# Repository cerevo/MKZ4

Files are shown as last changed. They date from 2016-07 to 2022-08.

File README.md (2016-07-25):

MKZ4
====

ワイルドミニ四駆改造キット「MKZ4」用のマニュアル、サンプルプログラム、回路図などをまとめたレポジトリです。

## Folder structure
**Cerevo_MKZ4** ：サンプルプログラム。  
**custom** ：改造用のプログラムや、オリジナルボディのSTLデータ。  
**manual** ：キット付属のマニュアル。  
**schematic**:回路図。  

## Requirement
サンプルプログラムの使用にはVer1.6.8の[Arduino IDE](https://www.arduino.cc/en/Main/OldSoftwareReleases#previous)と[ESP8266 core for Arduino](https://github.com/esp8266/Arduino)のインストールが必要です。  
インストールの説明はそれぞれのURLを参照してください。

## Demo
/Cerevo_MKZ4/Cerevo_MKZ4.inoがサンプルプログラムになります。  
ESP8266を追加したArduino IDEでビルドしてください。  
※ボードマネージャーのesp8266のVerは2.2.0で動作確認をしています。  

## Licence

[BSD 3-Clause License](https://opensource.org/licenses/BSD-3-Clause)

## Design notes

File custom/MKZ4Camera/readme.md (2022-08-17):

# About
MKZ4にESP32カメラを接続し、カメラの画像を見ながらラジコン操作ができるプロジェクトです。
M5 cameraXにて動作確認をしています。他のデバイスを使う場合はCameraWebServer.ino内で対象のカメラモデルを選択してください。

MKZ4との接続は以下の通りです。また[Cervoブログの記事](https://tech-blog.cerevo.com/archives/12014/)も参照してみてください。（制作的なことはざっくりとしか書いていないです。すみません。）

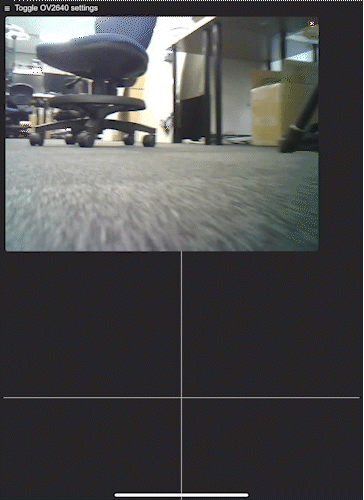
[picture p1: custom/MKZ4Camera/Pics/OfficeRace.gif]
Office Circuit


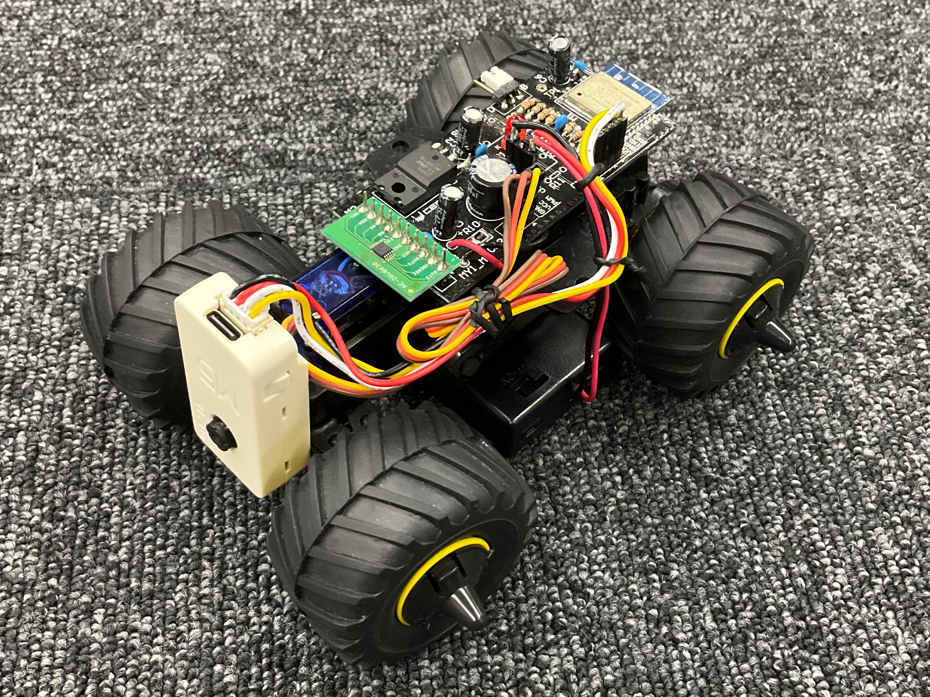
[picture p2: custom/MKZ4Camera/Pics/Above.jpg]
View from above


## System
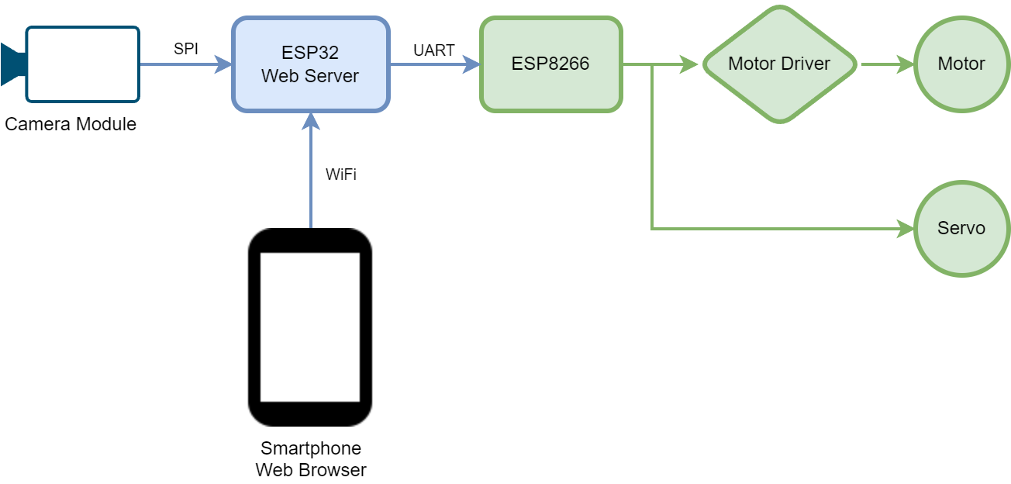
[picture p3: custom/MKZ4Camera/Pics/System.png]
System


## Important Note
- 電源スイッチを入れるときにEP32とUART端子が接続されているとMKZ4基板が起動しない（LEDが点灯しない）ため、UART端子を外してから電源スイッチを入れ、それからUART端子を再度接続するようにしてください。
- Arduino環境でArduino-ESP32をセットアップする場合、package_esp32_index.jsonのダウンロード先に注意してください。古い資料だと以下のURLになっていますが、ESP32 Arduino v1.0.6以降更新されていないようです。
`https://dl.espressif.com/dl/package_esp32_index.json`
Espressifのドキュメンテーションにあるとおり、以下のURLを設定する必要があります。
`https://docs.espressif.com/projects/arduino-esp32/en/latest/installing.html`
古いindex.jsonのURLが入っているとArduino-ESP32のバージョンがアップデートされず、ビルド出来なくなります。

## Building Project
- MKZ4(ESP8266)のプロジェクト（Cerevo_MKZ4_UARTまたはCerevo_MKZ4_UART_platformio）をビルドする。
- ESP32カメラのプロジェクトをビルドする（CameraWebServerまたはMKZ4_Camera_ESP32_platformio)
- ビルド方法はそれぞれのフォルダ内のReadme参照

## Wiring
ESP32カメラ（Grobeコネクタ）とMKZ4を以下のように接続します。
| ESP32カメラ(Grobe) | MKZ4  |
| --- |---|
| Pin1(Yellow) | TDX |
| Pin2(White) | RDX |
| Pin3(Black) | GND |
| Pin4(Red) | Batt+ |

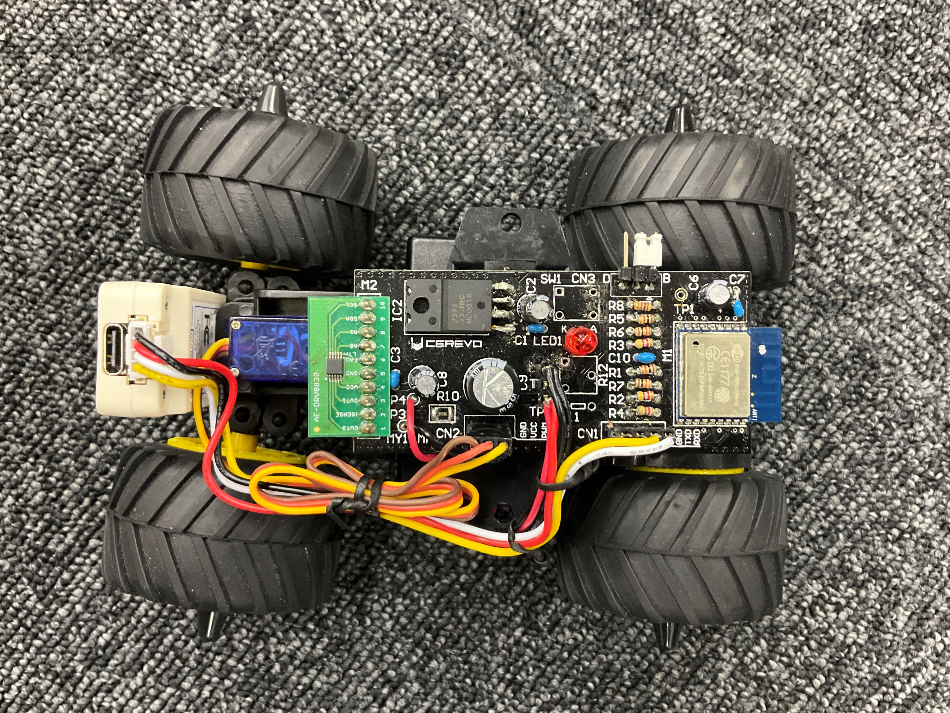
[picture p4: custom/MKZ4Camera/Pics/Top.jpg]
Top

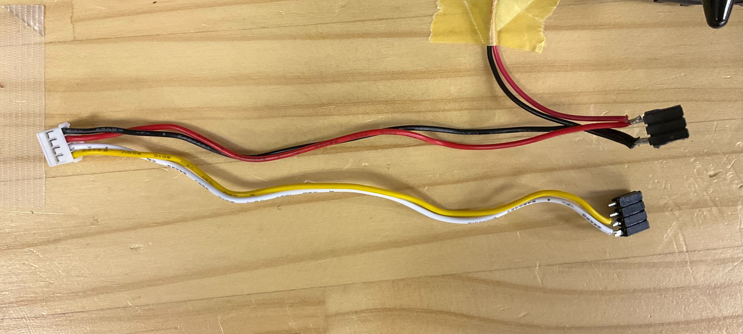
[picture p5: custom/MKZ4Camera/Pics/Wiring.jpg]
Wiring


## セットアップ起動手順
- 上記Wiringを済ませ配線したらMKZ4側のUART端子を外しておく
- 電池ボックスの電源を入れる
- MKZ4基板上のLED点灯を確認する。
- UART端子を接続
- AP接続の場合mkz4camというWiFiアクセスポイントがスマートフォンから見えるはずなので接続する。PW不要、インターネットに接続されていないと警告が出るかもしれませんが無視します。
- Webブラウザを立ち上げ、**192.168.4.1** と入力すると操作画面が見えます。
- Settingsタブを開き、一番下のStartStreamボタンを押すとESP32Cameraの画像が見えます。
- 画面下部の十字エリア中心部をタッチし（指を離さないまま）上の方にスライドします。MKZ4のモーターが回りましたか？
- 同様に左右方向に指をスライドさせるとステアリングが動きます。
- 下方向にスライドさせるとモーターが反転して回ります。

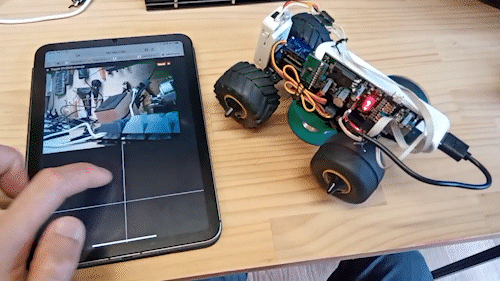
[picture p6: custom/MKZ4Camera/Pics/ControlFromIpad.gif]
From Ipad


## 技術情報
[M5 cameraX pinout](https://docs.m5stack.com/en/unit/m5camera_x)

今回参照したカメラウェブサーバのサンプルです。ESP32版もあります。
[Official CameraWebServer.ino sample](https://github.com/espressif/arduino-esp32/tree/master/libraries/ESP32/examples/Camera/CameraWebServer)

[ESP-IDFでのWebsocket実装情報](https://docs.espressif.com/projects/esp-idf/en/latest/esp32/api-reference/protocols/esp_http_server.html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)

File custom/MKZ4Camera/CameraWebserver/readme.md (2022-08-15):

# About
MKZ4にESP32カメラを接続し、カメラの画像を見ながらラジコン操作ができるプロジェクトです。
M5 cameraXにて動作確認をしています。他のデバイスを使う場合はCameraWebServer.ino内で対象のカメラモデルを選択してください。
MKZ4との接続は以下の通りです。またCervoブログの記事も参照してみてください。（制作的なことはざっとしか書いてないです。すみません。）

## Important Note
- 電源スイッチを入れるときにEP32とUART端子が接続されているとMKZ4基板が起動しない（LEDが点灯しない）ため、UART端子を外してから電源スイッチを入れ、それからUART端子を再度接続するようにしてください。
- Arduino環境でArduino-ESP32をセットアップする場合、package_esp32_index.jsonのダウンロード先に注意してください。古い資料だと以下のURLになっていますが、ESP32 Arduino v1.0.6以降更新されていないようです。
`https://dl.espressif.com/dl/package_esp32_index.json`
Espressifのドキュメンテーションにあるとおり、以下のURLを設定する必要があります。
`https://docs.espressif.com/projects/arduino-esp32/en/latest/installing.html`
古いindex.jsonのURLが入っているとArduino-ESP32のバージョンがアップデートされず、ビルド出来なくなります。

## Build
- [Arduino-ESP32環境](https://docs.espressif.com/projects/arduino-esp32/en/latest/installing.html)をセットアップ
- WIFIAP_ENABLEDを有効にしていると（デフォルト）espcamのWiFiアクセスポイントが立ちあがります。自分のWiFiにつなぎたい場合はWIFIAP_ENABLEDを無効にしたうえでssid, passwordを入力してください。
- Tools > Board > ESP32 Wrover Moduleを選択
- Verify、Upload
- 追加ライブラリは特に必要ありません。

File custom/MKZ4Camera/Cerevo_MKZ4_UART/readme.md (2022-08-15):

# Cerevo MKZ4 controller with UART
こちらのスケッチはMKZ4をESP32カメラから操作するためのものです。このプログラムはUART経由で制御が可能です。

## Important Note
電源スイッチを入れるときにUART端子が接続されているとMKZ4基板が起動しない（LEDが点灯しない）ため、UART端子を外してから電源スイッチを入れ、それからUART端子を再度接続するようにしてください。

## How to build
オリジナルのMKZ4と同じくボードマネージャからESP8266を選択してVerifyしたあと、Uploadしてください。特に追加のライブラリは必要ありません。

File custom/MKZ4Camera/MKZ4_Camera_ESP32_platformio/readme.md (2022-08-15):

# About
MKZ4にESP32カメラを接続し、カメラの画像を見ながらラジコン操作ができるプロジェクトです。
M5 cameraXにて動作確認をしています。他のデバイスを使う場合はCameraWebServer.ino内で対象のカメラモデルを選択してください。
MKZ4との接続は以下の通りです。またCervoブログの記事も参照してみてください。（制作的なことはざっとしか書いてないです。すみません。）

## Important Note
- 電源スイッチを入れるときにEP32とUART端子が接続されているとMKZ4基板が起動しない（LEDが点灯しない）ため、UART端子を外してから電源スイッチを入れ、それからUART端子を再度接続するようにしてください。

## Build
- VSCodeからPlatformioをインストールしてください。
- PlatformIO: Buildでビルド
- PlatformIO: Upload
- 追加ライブラリは特に必要ありません。

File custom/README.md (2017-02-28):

## Description

- Cerevo_MKZ4_CDS_V02 :本体にLEDとCDSを追加して、暗くなったら自動でLEDが点灯するサンプル。

- Cerevo_MKZ4_LED-light :本体にLEDを追加してPWMで点灯させるサンプル。  

- Cerevo_MKZ4_LED-light2 :本体にLEDライト（フロントのみを想定）追加して走行時明るく光らせるサンプル。

- Cerevo_MKZ4_calib :UARTからoffset,left,rightの値を修正できるコマンドを追加。

- milkcocoa_esp8266 ：milkcocoaを使うサンプル(ESP側）。  

- milkcocoa_javascript ：milkcocoaを使うサンプル(javascript側)。  

- MKZ4_example2 :スマートフォンの傾きでミニ四駆を操作するサンプル。  

- remote_led_switch_example :ブラウザからLEDをON/OFFするサンプル。  

- MKZ4_OriginalBody.stl :オリジナルボディの3DCADのデータ。  

---
### キャリブコマンドの使い方

#### 前準備

1. Cerevo_MKZ4_calib.inoを書きこむ
2. ESP8266とUARTで接続する(ボーレート:115200 , デリミタ:CR+LF)

#### コマンド

* offset角度修正コマンド:前進させた時に少し右や左に曲がってしまうのを修正する  

コマンド  
offset+space+角度[CR][LF]  

ex)  
offset 10[CR][LF] //10°右にずらす  
offset -20[CR][LF] //20°左にずらす   
  
* 左ステアリング角度修正コマンド:左に曲がる角度を修正する　デフォルト65°

コマンド  
left+space+角度[CR][LF]  

ex)  
left 60[CR][LF] //左ステアリング角度を浅くする場合  
left 70[CR][LF] //左ステアリング角度を深くする場合  
   
* 右ステアリング角度修正コマンド:右に曲がる角度を修正する　デフォルト110°  

コマンド  
right+space+角度[CR][LF]  

ex)  
right 105[CR][LF] //右ステアリング角度を浅くする場合   
right 115[CR][LF] //右ステアリング角度を深くする場合

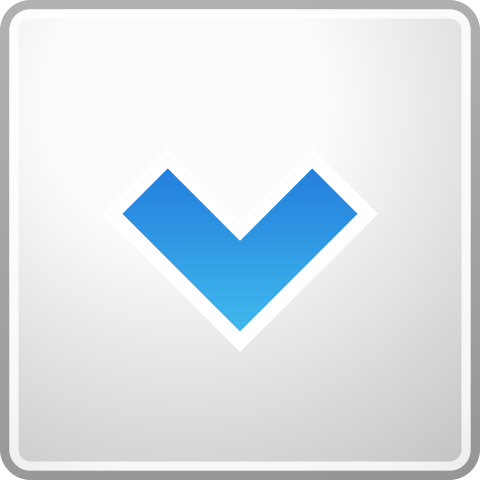
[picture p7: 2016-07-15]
custom/milkcocoa_javascript/image/back.png

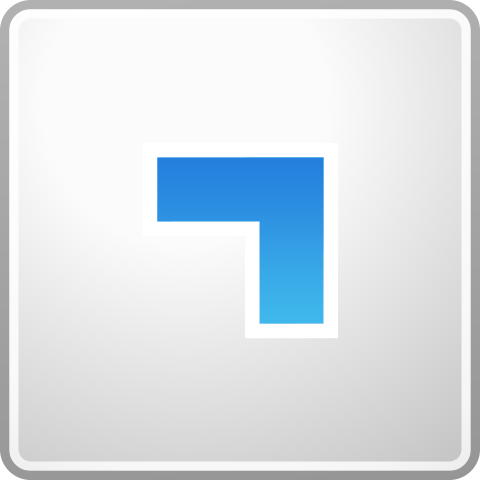
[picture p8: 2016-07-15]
custom/milkcocoa_javascript/image/f_right.png

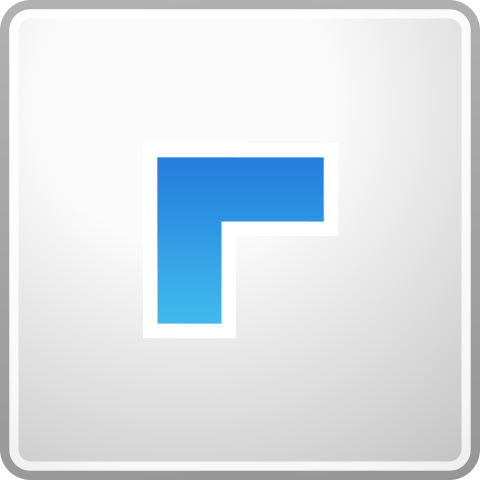
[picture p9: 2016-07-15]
custom/milkcocoa_javascript/image/f_left.png

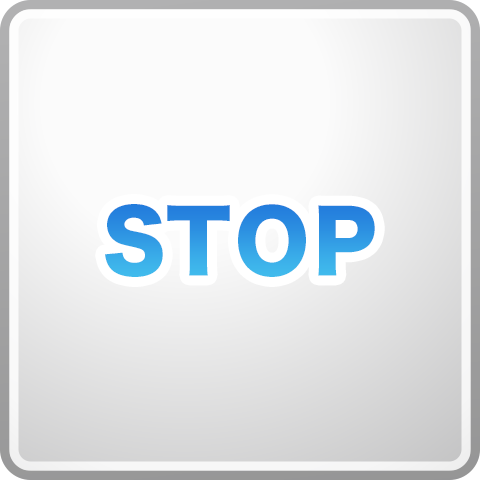
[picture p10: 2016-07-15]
custom/milkcocoa_javascript/image/stop.png

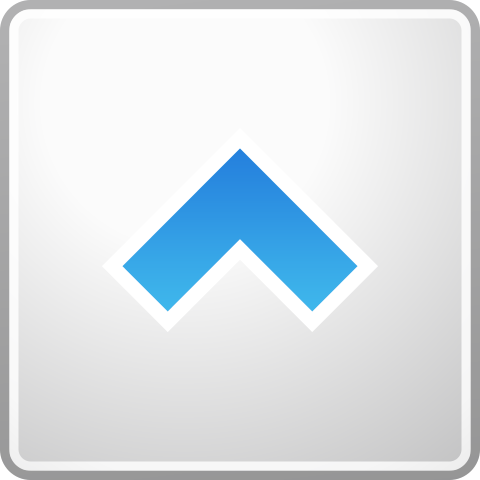
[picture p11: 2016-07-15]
custom/milkcocoa_javascript/image/forward.png

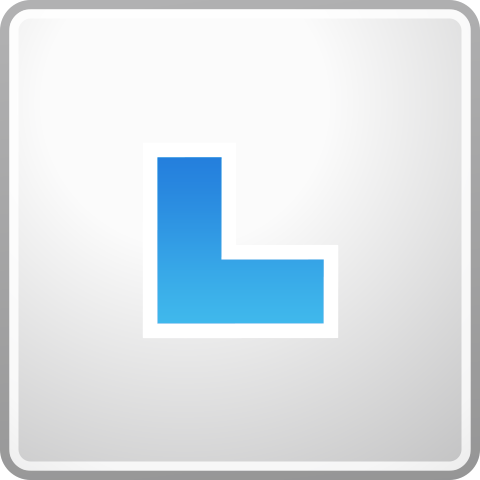
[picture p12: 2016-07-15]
custom/milkcocoa_javascript/image/b_left.png

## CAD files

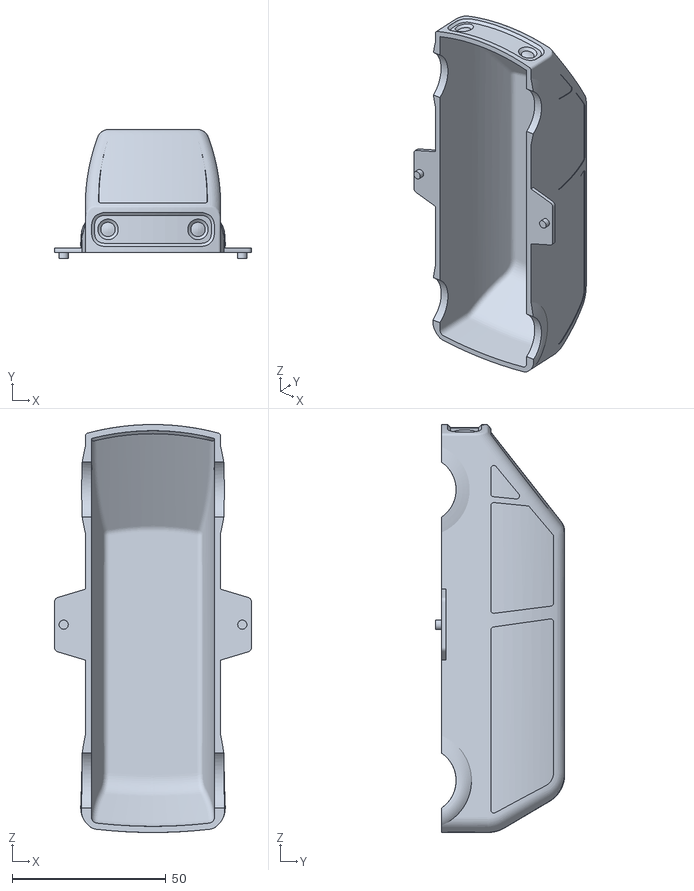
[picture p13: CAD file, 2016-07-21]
custom/MKZ4_OriginalBody.stl
64.0 x 42.0 x 132.5

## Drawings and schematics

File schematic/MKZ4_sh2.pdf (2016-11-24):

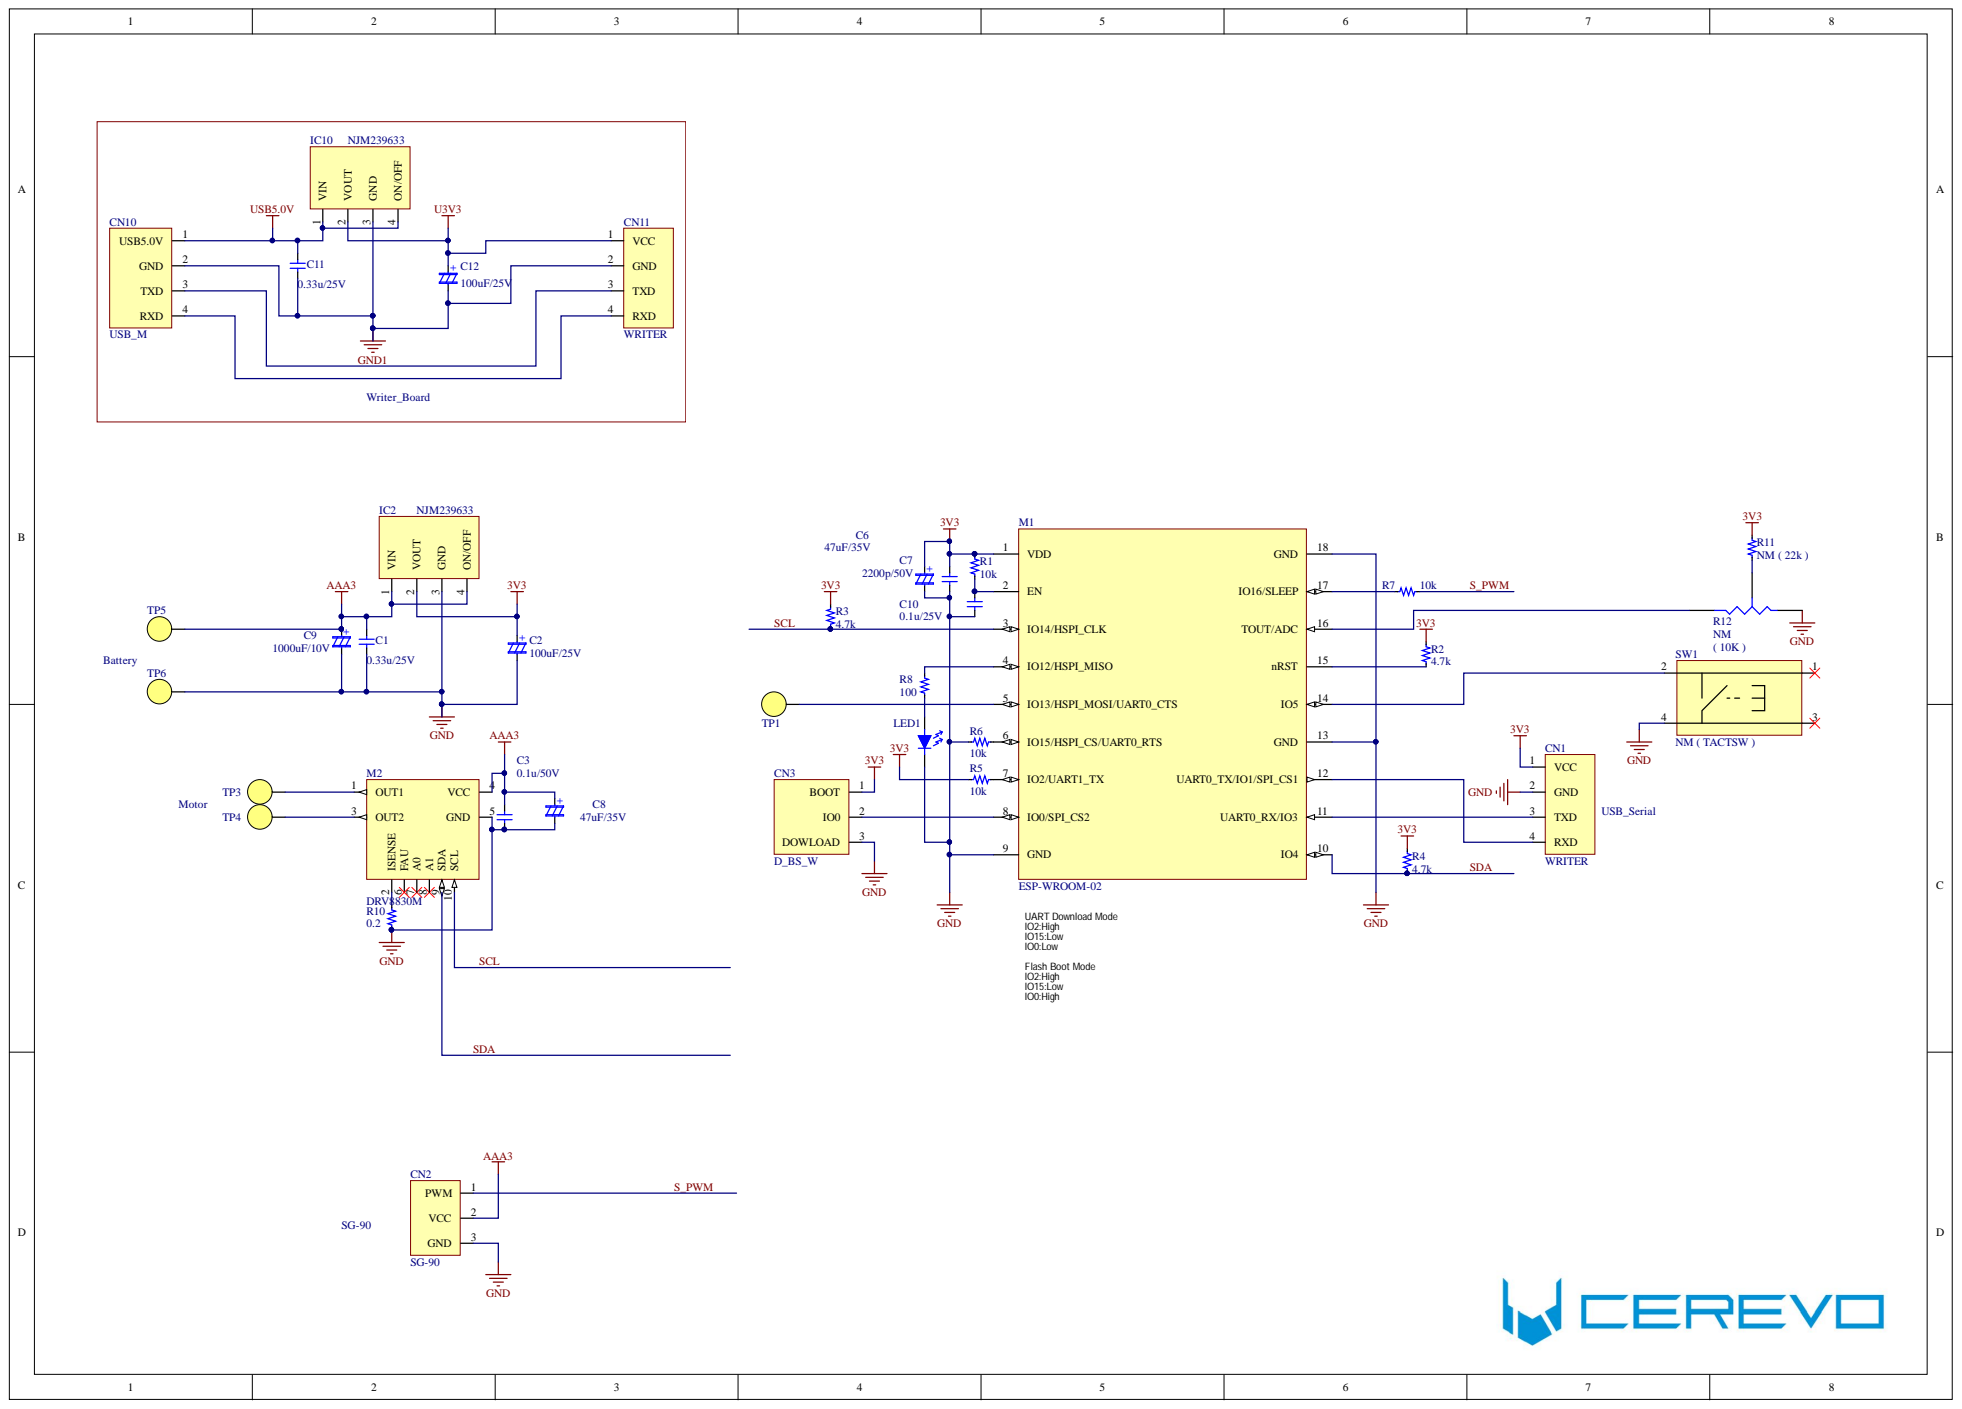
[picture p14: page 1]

UART Download Mode IO2:High IO15:Low

IO0:Low
Flash Boot Mode IO2:High
IO15:Low IO0:High

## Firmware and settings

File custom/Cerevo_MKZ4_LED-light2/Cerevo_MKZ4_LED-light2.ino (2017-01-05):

/*
 * Copyright (c) 2015, Majenko Technologies
 * All rights reserved.
 * 
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
 * * Neither the name of Majenko Technologies nor the names of its
 *   contributors may be used to endorse or promote products derived from
 *   this software without specific prior written permission.
 * 
 * THIS SOFTWARE IS PROVIDED BY THE COPYRIGHT HOLDERS AND CONTRIBUTORS "AS IS" AND
 * ANY EXPRESS OR IMPLIED WARRANTIES, INCLUDING, BUT NOT LIMITED TO, THE IMPLIED
 * WARRANTIES OF MERCHANTABILITY AND FITNESS FOR A PARTICULAR PURPOSE ARE
 * DISCLAIMED. IN NO EVENT SHALL THE COPYRIGHT HOLDER OR CONTRIBUTORS BE LIABLE FOR
 * ANY DIRECT, INDIRECT, INCIDENTAL, SPECIAL, EXEMPLARY, OR CONSEQUENTIAL DAMAGES
 * (INCLUDING, BUT NOT LIMITED TO, PROCUREMENT OF SUBSTITUTE GOODS OR SERVICES;
 * LOSS OF USE, DATA, OR PROFITS; OR BUSINESS INTERRUPTION) HOWEVER CAUSED AND ON
 * ANY THEORY OF LIABILITY, WHETHER IN CONTRACT, STRICT LIABILITY, OR TORT
 * (INCLUDING NEGLIGENCE OR OTHERWISE) ARISING IN ANY WAY OUT OF THE USE OF THIS
 * SOFTWARE, EVEN IF ADVISED OF THE POSSIBILITY OF SUCH DAMAGE.
 */

/* Create a WiFi access point and provide a web server on it. */

#include <ESP8266WiFi.h>
#include <WiFiClient.h> 
#include <ESP8266WebServer.h>

/* Set these to your desired credentials. */
const char *ssid = "MKZ4_Light2_**";
const char *password = "";

ESP8266WebServer server(80);
ESP8266WebServer server_8080(8080);

/* set I2C library*/
#include <Wire.h>
#define ADDR1  0x64

#define command_start  0
#define command_stop   1
#define command_back  2
#define forward       0x01
#define reverse       0x02
#define servo_left    65
#define servo_right   115

#define LED_H       (digitalWrite( 12, HIGH ))
#define LED_L       (digitalWrite( 12, LOW ))

//TP1 GPIO13
#define HLED_H       (analogWrite( 13, 0 ))
#define HLED_M       (analogWrite( 13, 768 ))

char state = command_stop;
int offset = 0;

String form ="<html>"
"<head>"
"<meta name=\"viewport\" content=\"width=device-width, initial-scale=1, minimum-scale=1, maximum-scale=1\">"
"<style>"
"* { padding: 0; margin: 0; }"
"body { background-color: #0097C1; }"
"</style>"
"</head>"
"<body>"
"<div style=\"position:fixed;top: 50pt; text-align:center; width: 100%; color:white; font-size:300%; font-weight:bold; text-transform:uppercase; font-family:sans-serif\" id=\"value\">connected</div>"
"<form action=\"\" target=\"tif\" id=\"form\">"
"<iframe src=\"javascript: false;\" style=\"display: none;\" name=\"tif\" id=\"tif\"></iframe>"
"</form>"
"<script>"
"var offset = 50;"
"document.body.style.height = document.body.clientHeight + offset + \'px\';"
"document.body.style.width = document.body.clientWidth + offset + \'px\';"
"document.getElementsByTagName(\"html\")[0].style.height = document.body.style.height + \'px\';"
"document.getElementsByTagName(\"html\")[0].style.width = document.body.style.width + \'px\';"
"var moveHomePosition = function() {"
    "document.body.scrollTop = offset / 2;"
    "document.body.scrollLeft = offset / 2;"
"};"
"setTimeout(moveHomePosition, 500);"
"var startX = 0;var startY = 0;var command =\'/stop\';"
"var threshold = 40;"
"var esp_port = \'http://192.168.4.1:8080\';"
"var el_form = document.getElementById(\'form\');"
"document.body.ontouchstart = function(event) {"
    "startX = event.touches[0].clientX;"
    "startY = event.touches[0].clientY;"
"};"
"document.body.ontouchmove = function(event) {"
    "var x = parseInt(event.touches[0].clientX - startX);"
    "var y = parseInt(event.touches[0].clientY - startY);"
    "var url = null;"
    "if (x < (threshold * -1)) {"
       "if (y < (threshold * -1)){"
          "url = \'/left<br>forward\';"
       "} else if (y > threshold) {"
          "url = \'/left<br>back\';"
       "}else {"
        "url = \'/left\';"
       "}"
    "} else if (x > threshold) {"
       "if (y < (threshold * -1)) {"
          "url = \'/right<br>forward\';"
      "} else if (y > threshold) {"
          "url = \'/right<br>back\';"
      "}else{"
          "url = \'/right\';"
      "}"
     "} else {"
        "if (y < (threshold * -1)) {"
            "url = \'/forward\';"
        " } else if (y > threshold) {"
            "url = \'/back\';"
        "}"
     "}"
    "if (command != url) {"
      "if (url) {"
          "el_form.action = esp_port + url.replace(\"<br>\",\"\");"
          "el_form.submit();"
          "document.getElementById(\'value\').innerHTML = url.replace(\"/\",\"\");"
      "}"
    "}"
    "command = url;"
"};"
"document.body.ontouchend = function(event) {"
    "el_form.action = esp_port + \'/stop\';"
    "el_form.submit();"
    "setTimeout(moveHomePosition, 50);"
   "document.getElementById(\'value\').innerHTML = \'stop\';"
"};"
"</script>"
"</body>"
"</html>";

/* Just a little test message.  Go to http://192.168.4.1 in a web browser
 * connected to this access point to see it.
 */
void setup() {
	delay(1000);
	Serial.begin(115200);
	Serial.println();
	Serial.print("Configuring access point...");

  Wire.begin(4, 14);
  delay(40);
  
	/* You can remove the password parameter if you want the AP to be open. */
	WiFi.softAP(ssid, password);

	IPAddress myIP = WiFi.softAPIP();
	Serial.print("AP IP address: ");
	Serial.println(myIP);
 
	server.on("/", handleRoot);
  server_8080.on("/stop", handle_stop);
  server_8080.on("/forward", handle_forward);
  server_8080.on("/back", handle_back);
  server_8080.on("/left", handle_left);
  server_8080.on("/right", handle_right);
  server_8080.on("/leftforward", handle_f_left);
  server_8080.on("/rightforward", handle_f_right);
  server_8080.on("/leftback", handle_b_left);
  server_8080.on("/rightback", handle_b_right);
 
	server.begin();
  server_8080.begin();
  
	Serial.println("HTTP server started");
  pinMode(16,OUTPUT);
  pinMode(12,OUTPUT);

  LED_H;
  HLED_M;
    
  delay(100);
}

void loop() {
	server.handleClient();
  server_8080.handleClient();
}


void handleRoot() {
  server.send(200, "text/html", form);
}


void handle_stop() {
  Serial.print("stop\r\n");
  LED_L;
  HLED_M;
    stop_motor();
    state = command_stop;
  LED_H;
  server_8080.send(200, "text/html", "");
}

void handle_forward() {
 Serial.print("forward\r\n");
  HLED_H;
  drive();
  servo_control(90);
  server_8080.send(200, "text/html", "");
}

void handle_back() {
  Serial.print("back\r\n");
  HLED_H;
  back();
  servo_control(90);
}

void handle_left(){
  Serial.print("left\r\n");
  HLED_H;
  servo_control(servo_left);
  server_8080.send(200, "text/html", "");
}

void handle_right(){
  Serial.print("right\r\n");
  HLED_H;
  servo_control(servo_right);
  server_8080.send(200, "text/html", "");
}

void handle_f_left(){
  Serial.print("f_left\r\n");
  HLED_H;
  drive();
  servo_control(servo_left);
  server_8080.send(200, "text/html", "");
}

void handle_f_right(){
  Serial.print("f_right\r\n");
  HLED_H;
  drive();
  servo_control(servo_right);
 server_8080.send(200, "text/html", "");
}

void handle_b_left(){
  Serial.print("b_left\r\n");
  HLED_H; 
  back();
  servo_control(servo_left );
  server_8080.send(200, "text/html", "");
}


void handle_b_right(){
  Serial.print("b_right\r\n");
  HLED_H;
  back();
  servo_control(servo_right);
  server_8080.send(200, "text/html", "");
}

void drive(){
    if(state == command_back){
     stop_motor();

     delay(10);

     start_motor();
  
  }else if(state == command_stop){
    start_motor();
  }
  state = command_start;
}

void back(){
    if(state == command_start){
     stop_motor();
     delay(10);
     reverse_motor();
  }else if(state == command_stop){
    reverse_motor();
  }
  state = command_back;
}

void start_motor(){
  char i, volt;
  volt = 0x20;
  for(i=0;i<5;i++){ 
    volt = volt + ((0x40)*i);
    volt = volt | forward;
    motor_func(ADDR1 , volt);
    delay(10);
  }
}

void reverse_motor(){
    char i, volt;
  volt = 0x20;
  for(i=0;i<5;i++){ 
    volt = volt + ((0x40)*i);
    volt = volt | reverse;
    motor_func(ADDR1 , volt);
    delay(10);
  }
}

void stop_motor(){
  motor_func(ADDR1 , 0x18);
  delay(10);
  motor_func(ADDR1 , 0x1B);
  delay(10);
}

void motor_func(char add , char duty){
  Wire.beginTransmission(add);
  Wire.write(0x00);
  Wire.write(duty);
  Wire.endTransmission();
}

void servo_control(int angle){
int microsec,i;
      LED_L;
      microsec = (5*(angle+offset))+ 1000;
       
      for(i=0; i<20 ;i++){
        digitalWrite( 16, HIGH );
        delayMicroseconds( microsec ); 
        digitalWrite( 16, LOW );
        delayMicroseconds( 10000 - microsec ); 
      }
      LED_H;
}

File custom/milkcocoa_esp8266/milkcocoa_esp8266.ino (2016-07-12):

#include <ESP8266WiFi.h>
#include <Milkcocoa.h>


#include <Wire.h>
#define ADDR1  0x64

#define command_start  0
#define command_stop   1
#define command_back  2
#define forward       0x01
#define reverse       0x02

#define LED_H       (digitalWrite( 12, HIGH ))
#define LED_L       (digitalWrite( 12, LOW ))


char state = command_stop;
int offset = 0;

/************************* WiFi Access Point *********************************/

#define WLAN_SSID       "SSID_name"        //SSID名
#define WLAN_PASS       "SSID_pass"    //SSID パスワード


/************************* Your Milkcocoa Setup *********************************/

#define MILKCOCOA_APP_ID      "milkcocoa_app_id"   //milkcocoa idを記載
#define MILKCOCOA_DATASTORE   "data"            //milkcocoa data store 名を記載

/************* Milkcocoa Setup (you don't need to change this!) ******************/

#define MILKCOCOA_SERVERPORT  1883

/************ Global State (you don't need to change this!) ******************/

// Create an ESP8266 WiFiClient class to connect to the MQTT server.
WiFiClient client;

const char MQTT_SERVER[] PROGMEM    = MILKCOCOA_APP_ID ".mlkcca.com";
const char MQTT_CLIENTID[] PROGMEM  = __TIME__ MILKCOCOA_APP_ID;

Milkcocoa milkcocoa = Milkcocoa(&client, MQTT_SERVER, MILKCOCOA_SERVERPORT, MILKCOCOA_APP_ID, MQTT_CLIENTID);

void onpush(DataElement *elem) {
  int command;    //1:f_left 2:forward 3:f_right 0:stop 7:r_left 8:back 9:r_right
  
  Serial.println("onpush");
  command = elem->getInt("com");

  if(command == 1){
    handle_f_left();
  }else if(command == 2){
    handle_drive();
  }else if(command == 3){
    handle_f_right();
  }else if(command == 0){
    handle_stop();
  }else if(command == 7){
    handle_r_left();
  }else if(command == 8){
    handle_back();
  }else if(command == 9){
    handle_r_right();
  }

  
};

void setupWiFi() {
  Serial.println(); Serial.println();
  Serial.print("Connecting to ");
  Serial.println(WLAN_SSID);

  WiFi.begin(WLAN_SSID, WLAN_PASS);
  while (WiFi.status() != WL_CONNECTED) {
    delay(500);
    Serial.print(".");
  }
  Serial.println();

  Serial.println("WiFi connected");
  Serial.println("IP address: ");
  Serial.println(WiFi.localIP());
}

void setup() {
  Serial.begin(115200);
  delay(10);
  Serial.println("Milkcocoa SDK demo");

  Wire.begin(4, 14);
  delay(40);
  
  setupWiFi();

  pinMode(16,OUTPUT);
  pinMode(12,OUTPUT);
  
  Serial.println( milkcocoa.on(MILKCOCOA_DATASTORE, "push", onpush) );
};

void loop() {
  milkcocoa.loop();
  DataElement elem = DataElement();

  delay(2000);
};

void handle_stop() {
  Serial.print("stop\r\n");
  LED_H;
    stop_motor();
  LED_L;
    state = command_stop;
}

void handle_drive() {
 Serial.print("drive\r\n");
  LED_H;
  drive();
  servo_control(90);
  LED_L;
}

void handle_back() {
  Serial.print("back\r\n");
  back();
  servo_control(90);
}

void handle_left(){
  Serial.print("left\r\n");
   drive();
  servo_control(60);
}

void handle_right(){
  Serial.print("right\r\n");
   drive();
  servo_control(120);
}


void handle_f_left(){
  Serial.print("f_left\r\n");
  LED_H;
  drive();
  servo_control(60);
  LED_L;
}


void handle_f_right(){
  Serial.print("f_right\r\n");
  LED_H;
  drive();
  servo_control(120);
  LED_L;
}

void handle_r_left(){
  Serial.print("r_left\r\n");
  LED_H;
  back();
  servo_control(60);
  LED_L;
}


void handle_r_right(){
  Serial.print("r_right\r\n");
  LED_H;
  back();
  servo_control(120);
  LED_L;
}

void drive(){
    if(state == command_back){
    
     stop_motor();

     delay(10);

     start_motor();
  
  }else if(state == command_stop){
    start_motor();
  }
  state = command_start;
}

void back(){
    if(state == command_start){
    
     stop_motor();

     delay(10);

     reverse_motor();
  
  }else if(state == command_stop){
    reverse_motor();

  }
  state = command_back;
}

void start_motor(){
  char i, volt;
  volt = 0x20;
  for(i=0;i<5;i++){ 
    volt = volt + ((0x40)*i);
    volt = volt | forward;
    motor_func(ADDR1 , volt);
    delay(10);
  }
}

void reverse_motor(){
    char i, volt;
  volt = 0x20;
  for(i=0;i<5;i++){ 
    volt = volt + ((0x40)*i);
    volt = volt | reverse;
    motor_func(ADDR1 , volt);
    delay(10);
  }
   
}


void stop_motor(){
  motor_func(ADDR1 , 0x18);
  delay(10);

  motor_func(ADDR1 , 0x1B);
  delay(10);
}

void motor_func(char add , char duty){
  Wire.beginTransmission(add);
  Wire.write(0x00);
  Wire.write(duty);
  Wire.endTransmission();
}

void servo_control(int angle){
int microsec,i;

      microsec = (5*(angle+offset))+ 1000;
       
      for(i=0; i<20 ;i++){
        digitalWrite( 16, HIGH );
        delayMicroseconds( microsec ); 
        digitalWrite( 16, LOW );
        delayMicroseconds( 10000 - microsec ); 
      }
}

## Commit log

2016-07-08 add schematic
2016-07-12 カスタムソースを追加
2016-07-15 milkcocoaのhtmlファイル追加
2016-07-15 Add files via upload
    MKZ4_plus LED light control sketch
2016-07-21 外装のstlデータ追加
    [MKZ4_OriginalBody.stl]
2016-07-25 READMEを修正
2016-07-25 改行を修正
2016-07-25 ボードマネージャーの確認ver追加
2016-07-25 README修正
2016-07-25 ブラウザからLEDをON/OFFできるサンプルプログラム追加
2016-07-26 customフォルダ内のREADMEを追加
2016-07-26 custom/READMEに空行追加
2016-07-27 マニュアル誤字修正
2016-11-24 CN1 3pin - M1 11pin CN1 4pin - M1 12pin
    回路図の記載ミスを修正
    CN1 3pin - M1 11pin
    CN1 4pin - M1 12pin
    （基板と不一致）
2017-01-05 CDSで暗くなると光る作例
2017-01-05 返信時のポートが80になっていたので、8080に修正
2017-01-05 傾きから操作するスケッチのポートも80になっていたので、8080に修正
2017-01-06 追加サンプル説明
2017-01-06 改造作例サンプル追加
2017-02-28 UARTからoffset、LEFT,RIGHTの角度を修正できるコマンドを追加
2022-08-15 [Add] MKZ4 camera project added.
    [partitions.csv]
